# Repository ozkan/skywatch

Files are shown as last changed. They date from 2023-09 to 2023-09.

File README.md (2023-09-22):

# Skywatch

35% ergonomic ortholinear keyboard, powered by RP2040, along with OLED and hotswap sockets support 

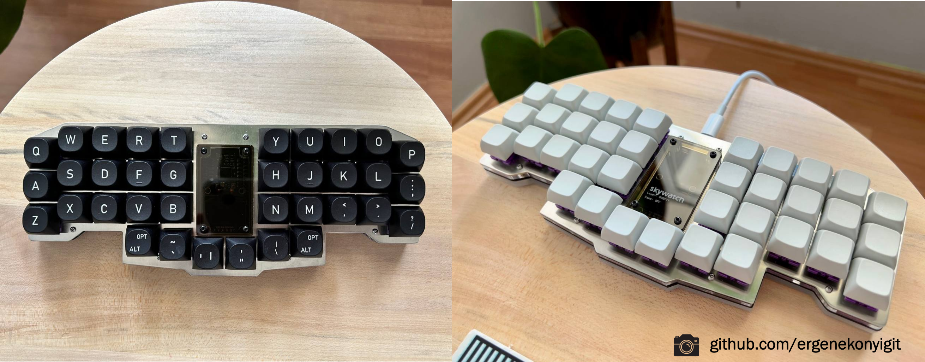
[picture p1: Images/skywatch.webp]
SKYWATC KEYBOARD

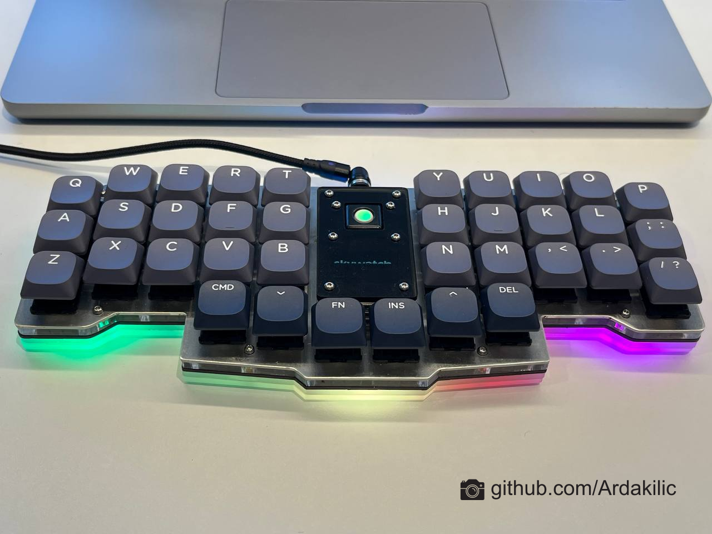
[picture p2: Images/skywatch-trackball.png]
SKYWATC KEYBOARD

### PCB Renders
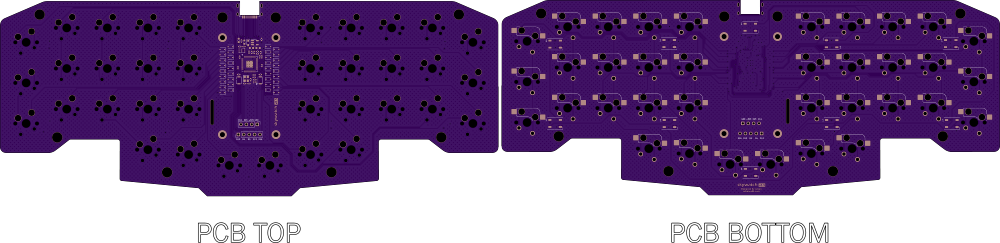
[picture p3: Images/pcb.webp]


### Bill of Materials
| Qty  | Descript |
|---|---|
| 1 | 0.96 inch IIC Serial 4pin OLED Display Module 128X64 (SSD1306) |
| 36 | Kailh Hot-swappable PCB socket Hot Plug (for MX Switch) |
| 10 | WS2812B RGB LED Chip 5050SMD |
| 1 | Type-C SMD USB Connectors (LCSC Part #C223906) |

### Cases (Acrylic plates)
| Qty  | Descript |
|---|---|
| 1 | [Swtich Plate (1.2mm aluminium, inox or acrylic)](Plate/) |
| 1 | [Upper Middle Plate (4mm acrylic)](Plate/) |
| 1 | [Lower Middle Plate (3mm acrylic)](Plate/) |
| 1 | [Bottom Plate (2mm or 3mm acrylic)](Plate/) |
| 1 | [Oled Cover (transparent or smoked acrylic)](Plate/) |
| 12 | M2x8mm Standoff/Spacer |
| 24 | M2x6mm Screw |
| 8 | Silicone Bumpers |

### Features
- Raspberry Pi RP2040 MCU
- 16MB flash memory (depending on component selection and availability)
- User LED & USB VBUS detect
- USB-C mid-mount connector
- Designed to be manufactured and assembled by common PCBA services
- The PCB has Kailh Hot-swappable sockets, so the switches can be swapped.
- 10x addressable (WS2812) underglow RGB led
- 128x64 Oled display 
- Trackball (optional) 

### Schematic
SKYWATC Schematic

### Firmware
[https://github.com/ozkan/Skywatch-QMK](https://github.com/ozkan/Skywatch-QMK)

### Finding Help

Have questions or need help, reach out via [our Telegram group](https://t.me/mechistanbul) where you will find many helpful Skywatch owners.

### Credits
- The design of this keyboard is based on the `0xB2 - splinky` board. Thanks [plut0nium](https://github.com/plut0nium)  
- Huge shoutout to [Arda Kılıçdağı ](https://github.com/Ardakilic) for tons of advice and help.

### Manufacturer
- [Özkan Çelik](https://github.com/ozkan)

### License
[MIT License](LICENSE)

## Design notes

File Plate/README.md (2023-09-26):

### Cases (Acrylic plates)

### Swtich Plate
1.2mm aluminium, inox, pcb or acrylic
switch plate

### Upper Middle Plate 
4mm acrylic
upper middle plate

### Lower Middle Plate 
3mm acrylic
lower middle plate

### Bottom Plate
2mm or 3mm acrylic

bottom plate                           

### Oled Cover                            
Transparent or smoked acrylic       
oled cover plate

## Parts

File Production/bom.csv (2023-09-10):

Designator | Footprint | Quantity | Value | LCSC Part #
_12, _11, _10, _9, _8, _7, _6, _5, _4, _3, _2, |  | 12
C1, C2 | 0603 | 2 | 1µ | C19666
C10, C11, C12, C13, C14, C7, C8, C9 | 0402 | 8 | 100n | C1525
C3, C4 | 0402 | 2 | 15p | C1548
C5, C6 | 0402 | 2 | 1µ | C52923
D1 | 0402 | 1 | LED | C130719
D10, D11, D12, D13, D14, D15, D16, D17, D18, D19, D20, D21, D22, D23, D24, D25, D26, D27, D28, D29, D3, D30, D31, D32, D33, D34, D35, D36, D37, D38, D4, D5, D6, D7, D8, D9 | D_SOD-323 | 36 | 1N4148W | C2843305
D2 | D_SOD-323 | 1 | B5817 | C123899
D39, D40, D41, D42, D43, D44, D45, D46, D47, D48 | LED_WS2812B_PLCC4_5.0x5.0mm_P3.2mm | 10 | WS2812B | C2843785
F1 | 0603 | 1 | Polyfuse | C69679
FB1 | 0603 | 1 | FerriteBead_Small | C98288
J1 | USB_C_Receptacle_HRO_TYPE-C-31-M-13B | 1 | USB_C_Receptacle_USB2.0 | C2848619
J2 | PinHeader_1x05_P2.54mm_Vertical | 1 | Conn_01x05_Female
J3 | PinHeader_1x04_P2.54mm_Vertical | 1 | Conn_01x04_Female
R1, R3, R8 | 0402 | 3 | 1k | C11702
R10, R4, R5 | 0402 | 3 | 5.1k | C25905
R11, R2, R9 | 0402 | 3 | 10k | C25744
R6, R7 | 0402 | 2 | 27 | C25100
SW1, SW2 | SW_SPST_CK_KXT3 | 2 | SW_Push | C319433
SW10, SW11, SW12, SW13, SW14, SW15, SW16, SW17, SW18, SW19, SW20, SW21, SW22, SW23, SW24, SW25, SW26, SW27, SW28, SW29, SW3, SW30, SW31, SW32, SW33, SW34, SW35, SW36, SW37, SW38, SW4, SW5, SW6, SW7, SW8, SW9 | MX_TH_HS_1U | 36 | MX_SW_HS
U1 | QFN-56-1EP_7x7mm_P0.4mm_EP3.2x3.2mm | 1 | RP2040 | C2040
U2 | USON-8-1EP_3x2mm_P0.5mm_EP0.25x1.65mm | 1 | GD25Q80CEIGR | C395484
U3 | SOT-23-5 | 1 | XC6210B332MR-G | C82942
Y1 | Crystal_SMD_2520-4Pin_2.5x2.0mm | 1 | Crystal_GND24 | C2149204

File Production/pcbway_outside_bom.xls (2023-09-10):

PCBWay Bom Quotation, Product No.: xxxxx
Item # | *Designator | *Qty | Manufacturer | *Mfg Part # | Description / Value | *Package/Footprint | Mounting Type | Your Instructions / Notes | *Unit Price(5 sets) | *Total | *Delivery Time | *PCBWay Note | Customer Reply | PCBWay Update
1 | R1,R3,R8 | 3 | UNI-ROYAL(Uniroyal Elec) | 0402WGF1001TCE | 62.5mW Thick Film Resistors ±100ppm/℃ ±1% 1kΩ 0402 Chip Resistor - Surface Mount ROHS | R_0402_1005Metric | SMD
2 | D2 | 1 | Shandong Jingdao Microelectronics | B5817WS | 20V 450mV@1A 1A SOD-323 Schottky Barrier Diodes (SBD) ROHS | D_SOD-323 | SMD
3 | D1 | 1 | Foshan NationStar Optoelectronics | NCD0402R1 | Red 0402 Light Emitting Diodes (LED) ROHS | LED_0402_1005Metric | SMD
4 | C10,C11,C12,C13,C14,C7,C8,C9 | 8 | Samsung Electro-Mechanics | CL05B104KO5NNNC | 6V 100nF X7R ±10% 0402 Multilayer Ceramic Capacitors MLCC - SMD/SMT ROHS | C_0402_1005Metric | SMD
5 | C3,C4 | 2 | FH (Guangdong Fenghua Advanced Tech) | 0402CG150J500NT | 50V 15pF C0G ±5% 0402 Multilayer Ceramic Capacitors MLCC - SMD/SMT ROHS | C_0402_1005Metric | SMD
6 | C1,C2 | 2 | Samsung Electro-Mechanics | CL10A475KO8NNNC | 16V 4.7uF X5R ±10% 0603 Multilayer Ceramic Capacitors MLCC - SMD/SMT ROHS | C_0603_1608Metric | SMD
7 | U1 | 1 | Raspberry Pi | RP2040 | 264KB 30 ARM-MSeries 133MHz LQFN-56(7x7) Microcontroller Units (MCUs/MPUs/SOCs) ROHS | QFN-56-1EP_7x7mm_P0.4mm_EP3.2x3.2mm | SMD
8 | Y1 | 1 | JYJE | 2TJ412000HYGBC | 12MHz 9pF ±10ppm SMD2520-4P Crystals ROHS | Crystal_SMD_2520-4Pin_2.5x2.0mm | SMD
9 | R6,R7 | 2 | UNI-ROYAL(Uniroyal Elec) | 0402WGF270JTCE | 62.5mW Thick Film Resistors ±100ppm/℃ ±1% 27Ω 0402 Chip Resistor - Surface Mount ROHS | R_0402_1005Metric | SMD
10 | R11,R2,R9 | 3 | UNI-ROYAL(Uniroyal Elec) | 0402WGF1002TCE | 62.5mW Thick Film Resistors ±100ppm/℃ ±1% 10kΩ 0402 Chip Resistor - Surface Mount ROHS | R_0402_1005Metric | SMD
11 | R10,R4,R5 | 3 | UNI-ROYAL(Uniroyal Elec) | 0402WGF5101TCE | 62.5mW Thick Film Resistors ±100ppm/℃ ±1% 5.1kΩ 0402 Chip Resistor - Surface Mount ROHS | R_0402_1005Metric | SMD
12 | D10,D11,D12,D13,D14,D15,D16,D17,D18,D19,D20,D21,D22,D23,D24,D25,D26,D27,D28,D29,D3,D30,D31,D32,D33,D34,D35,D36,D37,D38,D4,D5,D6,D7,D8,D9 | 36 | Slkor(SLKORMICRO Elec.) | 1N4148WS | 75V 350mW 1.25V 4ns 150mA SOD-323 Switching Diode ROHS | D_SOD-323 | SMD
13 | J1 | 1 | Korean Hroparts Elec | TYPE-C-31-M-13B | 5A 1 Sink board 16P Female -30℃~+80℃ Type-C SMD USB Connectors ROHS | USB_C_Receptacle_HRO_TYPE-C-31-M-13B | SMD
14 | SW1,SW2 | 2 | HYP (Hongyuan Precision) | 1TS015A-1400-0600-CT | No NO 0.6W 50mA 100MΩ 300000次 140gf@±30gf 12V Brick nogging SPST SMD,2x3mm Tactile Switches ROHS | SW_SPST_CK_KXT3 | SMD
15 | U2 | 1 | GigaDevice Semicon Beijing | GD25Q80CEIGR | USON-8_3x2mm NOR FLASH ROHS | USON-8-1EP_3x2mm_P0.5mm_EP0.25x1.65mm | SMD | If you do not have GD25Q80CEIGR in stock, you can use P25Q32H-UXH-IR instead.
16 | C5,C6 | 2 | Samsung Electro-Mechanics | CL05A105KA5NQNC | 25V 1uF X5R ±10% 0402 Multilayer Ceramic Capacitors MLCC - SMD/SMT ROHS | C_0402_1005Metric | SMD
17 | F1 | 1 | TECHFUSE | SMD0603-050 | 6V 500mA 40A 1A 0603 Resettable Fuses ROHS | Fuse_0603_1608Metric | SMD
18 | U3 | 1 | MICRONE(Nanjing Micro One Elec) | ME6211C33M5G-N | 500mA 70dB@(1kHz),62dB@(10kHz) Fixed 3.3V~3.3V Positive 6V SOT-23-5 Linear Voltage Regulators (LDO) ROHS | SOT-23-5 | SMD
19 | FB1 | 1 | Sunlord | PZ1608U600-2R5TF | 0.04Ω ±25% 60Ω@100MHz 0603 Ferrite Beads ROHS | L_0603_1608Metric
 |  |  |  |  |  |  |  |  | Component Cost
 |  |  |  |  |  |  |  |  | Assembly Cost
 |  |  |  |  |  |  |  |  | PCB Cost
 |  |  |  |  |  |  |  |  | V2 Member 2% off
 |  |  |  |  |  |  |  |  | All Total 5 Sets

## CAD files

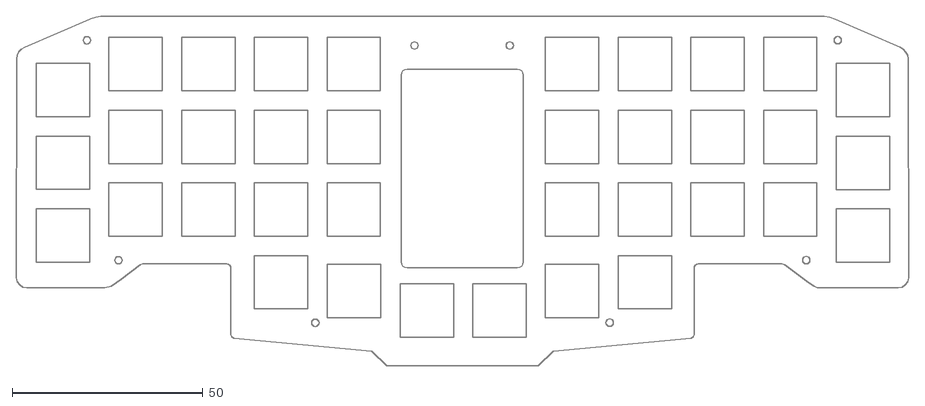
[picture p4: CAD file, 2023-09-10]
Plate/switch-plate.dxf
233.7 x 91.4

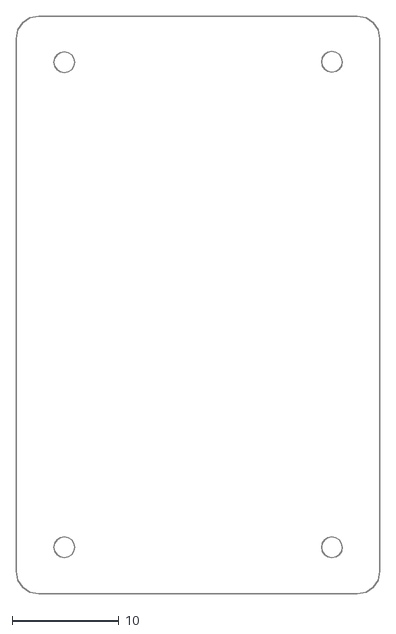
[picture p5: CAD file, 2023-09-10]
Plate/oled-cover.dxf
34.1 x 54.2

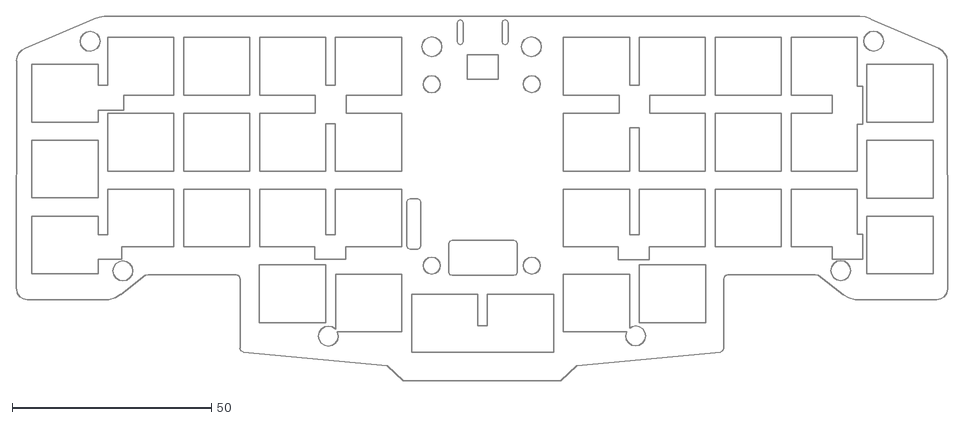
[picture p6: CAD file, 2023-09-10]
Plate/lower-middle-plate.dxf
233.7 x 91.5

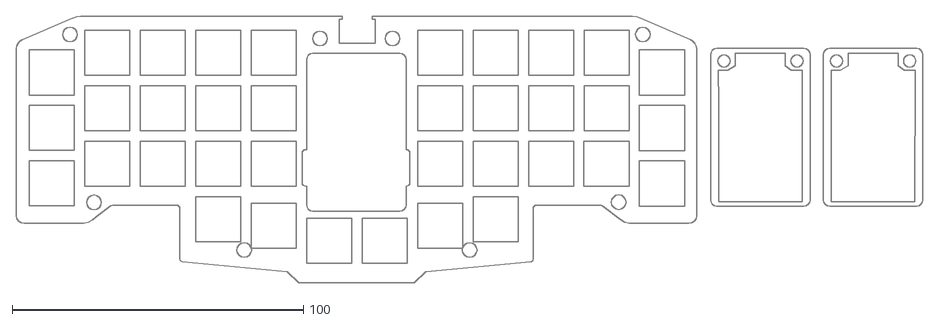
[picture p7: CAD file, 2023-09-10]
Plate/upper-middle-plate.dxf
311.3 x 91.4

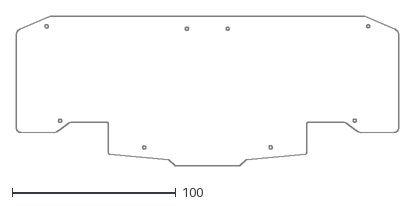
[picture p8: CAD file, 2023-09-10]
Plate/bottom-plate.dxf
233.7 x 91.4

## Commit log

2023-09-10 Add initial project files
    [bom.csv, bottom-plate.dxf, designators.csv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]
2024-01-29 up: pcb page settings
    [skywatch.kicad_sch]
